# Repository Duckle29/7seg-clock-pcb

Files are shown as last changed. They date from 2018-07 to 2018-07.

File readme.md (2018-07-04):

### A small PCB for stacking on a WemosD1-mini to control two strips of WS2812 LEDs

This board has been made to work with [this](https://www.thingiverse.com/thing:2947883) 7 segment clock. It uses 2 mosfets as level-shifters instead of the levelshifter chip originally used. It also incorporates the barrel-jack into the PCB

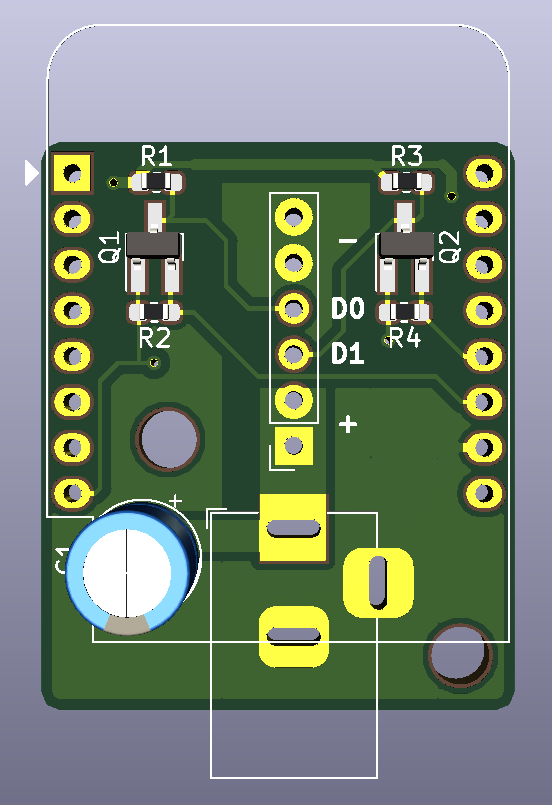
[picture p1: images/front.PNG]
front render
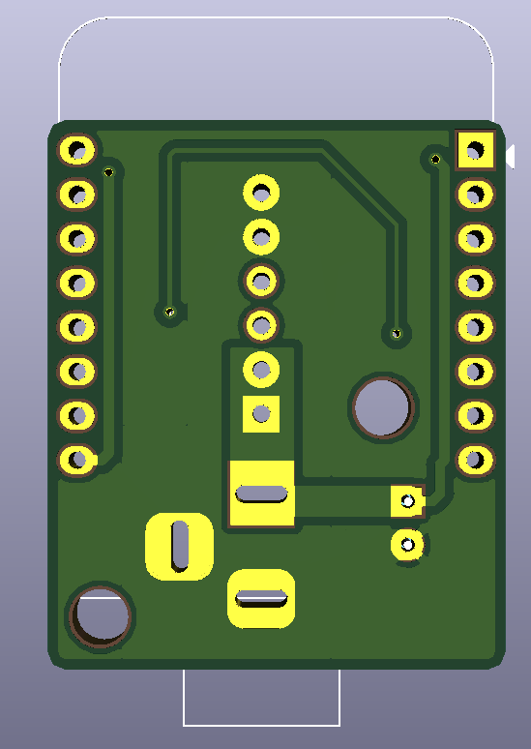
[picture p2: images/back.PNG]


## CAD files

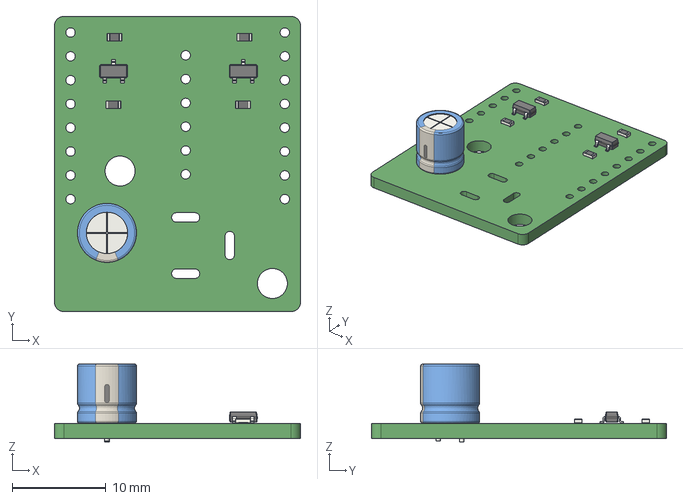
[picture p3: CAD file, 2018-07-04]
documentation/7seg-clock.stp
26.2 x 31.5 x 8.30 mm

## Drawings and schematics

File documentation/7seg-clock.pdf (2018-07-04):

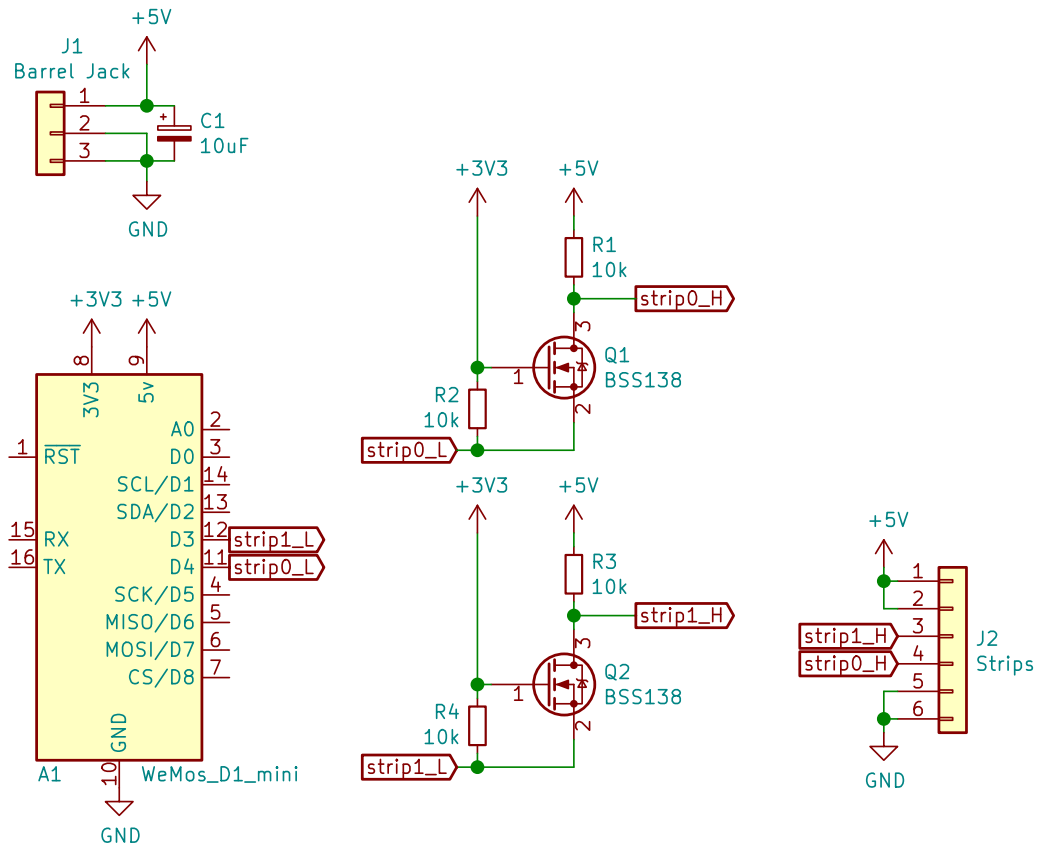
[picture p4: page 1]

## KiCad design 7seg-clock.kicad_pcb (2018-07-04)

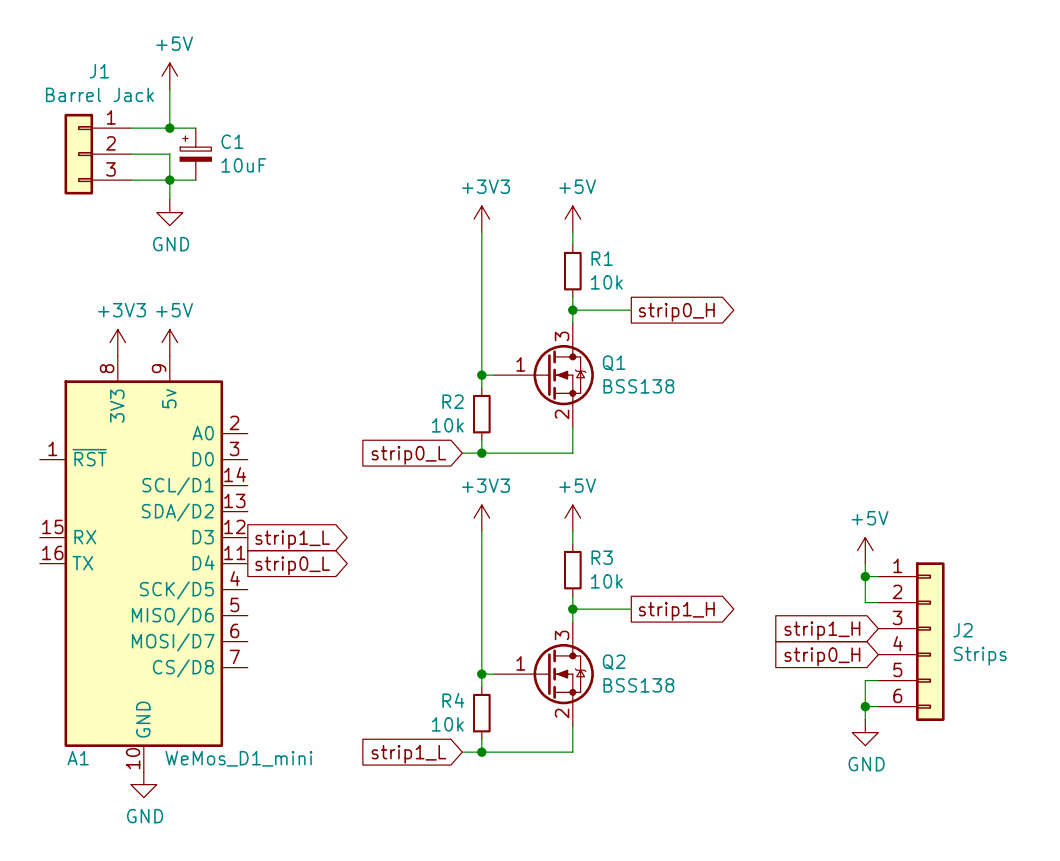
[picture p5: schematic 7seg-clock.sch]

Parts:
A1: WeMos_D1_mini
C1: 10uF; CP_Radial_D6.3mm_P2.50mm
J1: Barrel Jack; BarrelJack_Horizontal
J2: Strips; PinSocket_1x06_P2.54mm_Vertical
Q1, Q2: BSS138; SOT-23_Handsoldering
R1, R2, R3, R4: 10k; R_0603_1608Metric_Pad1.05x0.95mm_HandSolder

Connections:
+3V3: A1.8 (3V3), Q1.1 (G), Q2.1 (G), R2.2, R4.2
+5V: A1.9 (5v), C1.1, J1.1, J2.1, J2.2, R1.1, R3.1
GND: A1.10 (GND), C1.2, J1.2, J1.3, J2.5, J2.6
strip0_H: J2.4, Q1.3 (D), R1.2
strip0_L: A1.11 (D4), Q1.2 (S), R2.1
strip1_H: J2.3, Q2.3 (D), R3.2
strip1_L: A1.12 (D3), Q2.2 (S), R4.1

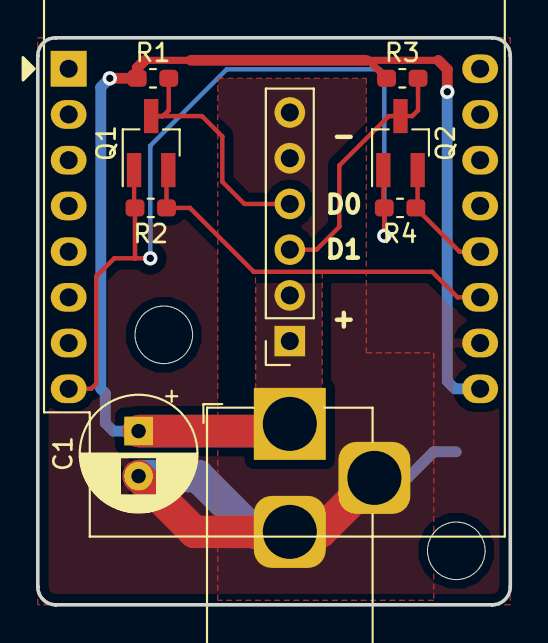
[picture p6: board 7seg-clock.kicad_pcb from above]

Board: 2 copper layers, 26.2 x 31.5 mm, 10 parts (0 on the bottom side), 7 nets.

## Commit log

2018-07-04 Added PDF of schematic
    [7seg-clock.sch]
2018-07-04 Moved docs and added 3D step file
    [7seg-clock.stp]
2018-07-04 Added gerbers
    [7seg-clock-B.Cu.gbl, 7seg-clock-B.Mask.gbs, 7seg-clock-B.SilkS.gbo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]
2018-07-04 Closed kicad, PCBnew asked to save
    [7seg-clock.kicad_pcb]
2018-07-04 Changed barrel-jack footprint to use holes instead of slots
    [7seg-clock-B.Cu.gbl, 7seg-clock-B.Mask.gbs, 7seg-clock-B.SilkS.gbo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]
